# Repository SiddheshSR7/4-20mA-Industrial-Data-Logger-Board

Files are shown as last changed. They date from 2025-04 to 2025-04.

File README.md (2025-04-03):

**Project Overview: 4-20mA Industrial IoT Data Logger**

The 4-20mA Industrial IoT Data Logger is a high-precision data acquisition system designed for industrial automation, remote monitoring, and predictive maintenance applications. Engineered with robust hardware and intelligent software, this 4-layer PCB is developed using KiCad and features advanced communication protocols, real-time data logging, and IoT connectivity. This system ensures accurate monitoring of industrial processes, enabling seamless data exchange and control in demanding environments.

### **Hardware Specifications:**
- **Microcontroller:** ESP32-WROOM-S3 SoC with dual-core Xtensa LX7 processor, integrated Wi-Fi & Bluetooth connectivity, and low-power operation.
- **USB-UART Interface:** CP2102N IC enabling high-speed USB-to-serial communication for seamless programming and debugging.
- **Analog Input:** 4-channel 4-20mA analog input with high-precision ADC for industrial sensor interfacing and real-time data acquisition.
- **Relay Output:** 2-channel 24VDC fast-switching relay outputs designed for industrial control applications, supporting up to 3A load per channel.
- **Communication Interfaces:**
  - **RS232 (Full-Duplex):** Supports legacy industrial communication standards for serial device interfacing.
  - **RS485 (Half-Duplex):** Enables reliable long-distance communication in noisy industrial environments.
- **Data Storage:** SD card interface supporting high-capacity storage for logging and offline data retrieval.
- **Programming & Debugging:**
  - USB B-type connector for easy programming and firmware updates.
  - Dedicated UART debug port for real-time monitoring, diagnostics, and firmware development.
- **Power Specifications:**
  - Operating voltage: 24V DC.
  - Maximum current rating: 3A.
  - Efficient power management ensuring stable performance in industrial environments.

### **Software Features:**
- **IoT Dashboard Integration:** Secure cloud-based monitoring and control via an interactive web-based dashboard.
- **Over-the-Air (OTA) Updates:** Supports remote firmware upgrades, reducing downtime and maintenance efforts.
- **Configurable I/O:** User-defined configuration for analog input scaling and relay output control through an intuitive software interface.
- **MQTT Protocol:** Enables encrypted and reliable cloud communication, facilitating seamless data transmission for industrial automation.
- **Data Logging & Analytics:**
  - Real-time and historical data storage for trend analysis and predictive maintenance.
  - Secure SD card-based local logging for offline diagnostics.
- **Multi-Protocol Support:** Compatible with Modbus RTU, MQTT, and HTTP APIs for enhanced industrial IoT integration.

### **Applications:**
- Industrial process monitoring and control.
- Remote asset tracking and condition monitoring.
- SCADA system integration.
- Energy and utility monitoring.
- Predictive maintenance and fault detection.

The 4-20mA Industrial IoT Data Logger is a powerful solution for industrial automation, offering real-time data acquisition, secure cloud connectivity, and seamless integration into existing systems. Its combination of rugged hardware and intelligent software makes it an ideal choice for modern industrial applications requiring high accuracy, reliability, and efficiency.

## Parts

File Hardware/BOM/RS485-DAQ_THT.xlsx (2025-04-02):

Sr. No. | Reference | Value | Footprint | Qty
1 | C1 | 100uF/6.3V | Capacitor_SMD:C_0805_2012Metric_Pad1.18x1.45mm_HandSolder | 1
2 | C2 | 1uF/50V | Capacitor_SMD:C_0805_2012Metric_Pad1.18x1.45mm_HandSolder | 1
3 | C3,C5 | 1nF/50V | Capacitor_SMD:C_0805_2012Metric_Pad1.18x1.45mm_HandSolder | 2
4 | C4 | 1uF/10V | Capacitor_SMD:C_0805_2012Metric_Pad1.18x1.45mm_HandSolder | 1
5 | C6,C8,C10 | 10uF/25V | Capacitor_SMD:C_0805_2012Metric_Pad1.18x1.45mm_HandSolder | 3
6 | C7,C9 | 0.1uF/25V | Capacitor_SMD:C_0805_2012Metric_Pad1.18x1.45mm_HandSolder | 2
7 | C11,C13,C15,C16,C17,C26 | 1uF | Capacitor_SMD:C_0805_2012Metric_Pad1.18x1.45mm_HandSolder | 6
8 | C12 | 470uF 35V | Capacitor_SMD:CP_Elec_10x10.5 | 1
9 | C14 | 100uF 16V | Capacitor_SMD:CP_Elec_8x10.5 | 1
10 | C18 | 100uF 10V | Capacitor_SMD:CP_Elec_8x6.9 | 1
11 | C19,C20,C21,C22 | 1nF | Capacitor_SMD:C_0805_2012Metric_Pad1.18x1.45mm_HandSolder | 4
12 | C23,C24 | 0.1uF | Capacitor_SMD:C_0805_2012Metric_Pad1.18x1.45mm_HandSolder | 2
13 | C25 | 100nF | Capacitor_SMD:C_0805_2012Metric_Pad1.18x1.45mm_HandSolder | 1
14 | C27 | 10uF | Capacitor_SMD:C_0805_2012Metric_Pad1.18x1.45mm_HandSolder | 1
15 | CR1 | M7 | Diode_SMD:D_1210_3225Metric_Pad1.42x2.65mm_HandSolder | 1
16 | D1,D2 | ESD9B5.0ST5G | Diode_SMD:D_SOD-923 | 2
17 | D3 | S3D | S3D:S3D | 1
18 | D4,D5,D6,D7 | SMAJ18A | Diode_SMD:D_SMA | 4
19 | D8,D9,D10,D11,D12,D13,D14,D15 | 1N5819 | Diode_SMD:D_1206_3216Metric_Pad1.42x1.75mm_HandSolder | 8
20 | D16,D17 | D_Zener | Diode_SMD:D_0805_2012Metric_Pad1.15x1.40mm_HandSolder | 2
21 | D18,D19 | LED | LED_SMD:LED_1206_3216Metric_Pad1.42x1.75mm_HandSolder | 2
22 | FB1,FB2,FB3,FB4 | FerriteBead | Inductor_SMD:L_Walsin_WLFM201209x | 4
23 | J1 | 10103594-0001LF | TypeBConnector:AMPHENOL_10103594-0001LF | 1
24 | J2 | UART | Connector_PinHeader_2.54mm:PinHeader_1x04_P2.54mm_Vertical | 1
25 | J3 | 24V Input | TerminalBlock_Phoenix:TerminalBlock_Phoenix_MPT-0,5-2-2.54_1x02_P2.54mm_Horizontal | 1
26 | J4 | Analog Input | TerminalBlock_Phoenix:TerminalBlock_Phoenix_MPT-0,5-5-2.54_1x05_P2.54mm_Horizontal | 1
27 | J5 | 2_Ch. AC Devices | TerminalBlock_Phoenix:TerminalBlock_Phoenix_MPT-0,5-4-2.54_1x04_P2.54mm_Horizontal | 1
28 | J6 | DB9 | Connector_Dsub:DSUB-9_Male_Horizontal_P2.77x2.84mm_EdgePinOffset4.94mm_Housed_MountingHolesOffset7.48mm | 1
29 | J7 | RS485 | TerminalBlock_Phoenix:TerminalBlock_Phoenix_MPT-0,5-2-2.54_1x02_P2.54mm_Horizontal | 1
30 | J8 | AC Input | TerminalBlock_Phoenix:TerminalBlock_Phoenix_MPT-0,5-3-2.54_1x03_P2.54mm_Horizontal | 1
31 | J9 | Micro_SD_Card | Connector_Card:microSD_HC_Wuerth_693072010801 | 1
32 | K1,K2 | Relay_SPDT | Relay_THT:Relay_SPDT_Finder_34.51_Vertical | 2
33 | L1 | 68uH | Inductor_SMD:L_Bourns_SRP1038C_10.0x10.0mm | 1
34 | Q1,Q2 | S8050 | Package_TO_SOT_THT:TO-92_Inline | 2
35 | R1,R6,R7 | 12K | Resistor_SMD:R_0805_2012Metric_Pad1.20x1.40mm_HandSolder | 3
36 | R2,R4 | 5K | Resistor_SMD:R_0805_2012Metric_Pad1.20x1.40mm_HandSolder | 2
37 | R3,R5,R12 | 470R | Resistor_SMD:R_0805_2012Metric_Pad1.20x1.40mm_HandSolder | 3
38 | R8,R9,R10,R11 | 0R | Resistor_SMD:R_0805_2012Metric_Pad1.20x1.40mm_HandSolder | 4
39 | R13,R14,R15,R16 | 250R | Resistor_SMD:R_0805_2012Metric_Pad1.20x1.40mm_HandSolder | 4
40 | R17,R19,R20 | 330 | Resistor_SMD:R_0805_2012Metric_Pad1.20x1.40mm_HandSolder | 3
41 | R18 | 300 | Resistor_SMD:R_0805_2012Metric_Pad1.20x1.40mm_HandSolder | 1
42 | R21,R22 | 1K | Resistor_SMD:R_0805_2012Metric_Pad1.20x1.40mm_HandSolder | 2
43 | R23 | 1k | Resistor_SMD:R_0805_2012Metric_Pad1.20x1.40mm_HandSolder | 1
44 | R24,R25,R26,R27 | 10k | Resistor_SMD:R_0805_2012Metric_Pad1.20x1.40mm_HandSolder | 4
45 | R28,R29 | 20k | Resistor_SMD:R_0805_2012Metric_Pad1.20x1.40mm_HandSolder | 2
46 | R30 | 120 | Resistor_SMD:R_0805_2012Metric_Pad1.20x1.40mm_HandSolder | 1
47 | RV1 | MOV-10D201K | MOV-10D201K:MOV10D201KTR | 1
48 | SW1,SW2 | SW_Push | Button_Switch_THT:SW_PUSH_6mm_H5mm | 2
49 | U1 | ESP32-WROOM-32D | RF_Module:ESP32-WROOM-32D | 1
50 | U2 | AMS1117-3.3 | Package_TO_SOT_SMD:SOT-223-3_TabPin2 | 1
51 | U3 | CP2102N-Axx-xQFN28 | Package_DFN_QFN:QFN-28-1EP_5x5mm_P0.5mm_EP3.35x3.35mm | 1
52 | U4 | LM2596S-12 | Package_TO_SOT_SMD:TO-263-5_TabPin3 | 1
53 | U5 | MAX232 | Package_SO:SOIC-16W_5.3x10.2mm_P1.27mm | 1
54 | U6 | AMS1117-5.0 | Package_TO_SOT_SMD:SOT-223-3_TabPin2 | 1
55 | U7,U8 | LM358 | Package_SO:SOIC-8_3.9x4.9mm_P1.27mm | 2
56 | U9,U10 | PC817 | Package_DIP:DIP-4_W7.62mm | 2
57 | U11 | MAX485E | Package_SO:SOIC-8_3.9x4.9mm_P1.27mm | 1
 |  |  | Total Qnty. | 109

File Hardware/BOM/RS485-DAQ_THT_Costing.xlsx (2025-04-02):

Reference | Value | Footprint | Qty | DNP | Unit Cost | Total/PCB | Purchase | Change
BT1 | Battery_Cell | Battery:BatteryHolder_Keystone_3034_1x20mm | 1 |  | 28 | 28 | https://in.element14.com/keystone/3034/batt-holder-coil-cell-20mm-x-1/dp/4049820
C1 | 100uF/6.3V | Capacitor_SMD:C_1206_3216Metric_Pad1.33x1.80mm_HandSolder | 1 |  | 12.1 | 12.1 | https://www.ktron.in/product/100uf-6-3v-multi-layered-ceramic-capacitor/?v=c86ee0d9d7ed
C2 | 1uF/50V | Capacitor_SMD:C_1206_3216Metric_Pad1.33x1.80mm_HandSolder | 1 |  | 2.1 | 2.1 | https://www.ktron.in/product/1uf-50v-multi-layered-ceramic-capacitor/?utm_term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
C3,C5 | 1nF/50V | Capacitor_SMD:C_1206_3216Metric_Pad1.33x1.80mm_HandSolder | 2 |  | 0.5 | 1 | https://www.ktron.in/product/1nf-50v-multi-layered-ceramic-capacitor-mlcc-smd-0603/?utm_term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
C4 | 1uF/10V | Capacitor_SMD:C_1206_3216Metric_Pad1.33x1.80mm_HandSolder | 1 |  | 1.06 | 1.06 | https://evelta.com/1uf-10v-10-x5r-0402-mlcc-multilayer-ceramic-capacitor-cl05a105kp5nnnc/?gad_source=1
C6,C8,C10,C12,C13,C14,C22 | 1uF | Capacitor_SMD:C_1206_3216Metric_Pad1.33x1.80mm_HandSolder | 7 |  | 3 | 21 | https://robu.in/product/1206b105k500nt-fh-50v-1uf-x7r%C2%B110-1206-multilayer-ceramic-capacitors-mlcc-smd-smt-rohs/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
C7 | 10uF/25V | Capacitor_SMD:CP_Elec_4x5.3 | 1 |  | 2 | 2 | https://www.ktron.in/product/25v-10uf-electrolytic-capacitor-smd/?utm_term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
C9 | 470uF 35V | Capacitor_SMD:CP_Elec_10x10.5 | 1 |  | 6 | 6 | https://robu.in/product/hy1v471mc100105meo-hyncdz-470uf-35v-480ma120hz-%C2%B120-smdd10xl10-5mm-aluminum-electrolytic-capacitors-smd-rohs/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
C11 | 100uF 16V | Capacitor_SMD:CP_Elec_8x10.5 | 1 |  |  | 0 |  | Y
C15 | 100uF 10V | Capacitor_SMD:CP_Elec_5x5.4 | 1 |  | 2 | 2 | https://robu.in/product/hy1a101mc050054meo-hyncdz-100uf-10v-50ma120hz-%C2%B120-smdd5xl5-4mm-aluminum-electrolytic-capacitors-smd-rohs/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
C16,C17,C18,C19 | 1nF | Capacitor_SMD:C_1206_3216Metric_Pad1.33x1.80mm_HandSolder | 4 |  | 6.61 | 26.44 | https://evelta.com/1-nf-500v-1206-smd-multilayer-ceramic-capacitors-cc1206kkx7rbbb102-yageo/
C20,C21 | 0.1uF | Capacitor_SMD:C_1206_3216Metric_Pad1.33x1.80mm_HandSolder | 2 |  | 2 | 4 | https://robu.in/product/0-1uf-capacitor-smdc-1206/
C23 | 10uF | Capacitor_SMD:C_1206_3216Metric_Pad1.33x1.80mm_HandSolder | 1 |  | 2 | 2 | https://robu.in/product/cs3216x7r106k160nri-samwha-16v-10uf-x7r-1206-multilayer-ceramic-capacitors-mlcc-smd-smt-rohs/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
CR1 | M7 | Diode_SMD:D_1210_3225Metric_Pad1.42x2.65mm_HandSolder | 1 |  | 1.36 | 1.36 | https://evelta.com/m7-1a-glass-passivated-rectifier-diode-sma/?gad_source=1
D1 | S3D | S3D:S3D | 1 |  | 17.5 | 17.5 | https://www.digikey.in/en/products/detail/diotec-semiconductor/S3D/21380521?productid=21380521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
D2,D3,D4,D5 | SMAJ18A | Diode_SMD:D_SMA | 4 |  | 7.5 | 30 | https://www.arrow.com/en/products/smaj18ar3g/taiwan-semiconductor
D6,D7,D8,D9,D10,D11,D12,D13 | 1N5819 | Diode_SMD:D_1206_3216Metric_Pad1.42x1.75mm_HandSolder | 8 |  | 4.64 | 37.12 | https://evelta.com/1n5819hw-7-f-40v-1a-schottky-barrier-rectifier-diode-2pin-sod123/?gad_source=1
D14,D15 | D_Zener | Diode_SMD:D_1206_3216Metric_Pad1.42x1.75mm_HandSolder | 2 |  | 2 | 4 | https://robu.in/product/bzv55-c24115-nexperia-zener-diode-24-v-500-mw-%C2%B15-surface-mount-sod-80-mini-melf-do-213ac-llds/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
D16,D17 | LED | LED_SMD:LED_1206_3216Metric_Pad1.42x1.75mm_HandSolder | 2 |  | 2.8 | 5.6 | https://evelta.com/green-led-smd-1206-package/?gad_source=1
FB1,FB2,FB3,FB4 | FerriteBead | Inductor_SMD:L_Walsin_WLFM201209x | 4 |  | 0.94 | 3.76 | https://robu.in/product/blm18ag121sn1d-murata-ferrite-beads-multi-layer-120ohm-25-100mhz-0-8a-0-18ohm-dcr-0603-t-r/ | Y
J1 | 24V Input | Connector_BarrelJack:BarrelJack_Horizontal | 1 |  | 1.96 | 1.96 | https://robu.in/product/dc-jack-005/?gad_source=1
J2 | Analog Input | TerminalBlock_Phoenix:TerminalBlock_Phoenix_MPT-0,5-5-2.54_1x05_P2.54mm_Horizontal | 1 |  |  | 0
J3 | 2_Ch. AC Devices | TerminalBlock_Phoenix:TerminalBlock_Phoenix_MPT-0,5-4-2.54_1x04_P2.54mm_Horizontal | 1 |  |  | 0
J4 | DB9 | Connector_Dsub:DSUB-9_Male_Horizontal_P2.77x2.84mm_EdgePinOffset4.94mm_Housed_MountingHolesOffset7.48mm | 1 |  | 12.39 | 12.39 | https://evelta.com/db9-male-connector-right-angle-pcb-mounting/?gad_source=1
J5 | RS485 | TerminalBlock_Phoenix:TerminalBlock_Phoenix_MPT-0,5-2-2.54_1x02_P2.54mm_Horizontal | 1 |  |  | 0
J6 | AC Input | TerminalBlock_Phoenix:TerminalBlock_Phoenix_MPT-0,5-3-2.54_1x03_P2.54mm_Horizontal | 1 |  |  | 0
K1,K2 | Relay_SPDT | Relay_THT:Relay_SPDT_hongfa-hf3ff | 2 |  | 34.22 | 68.44 | https://evelta.com/hongfa-hf3ff-series-10a-spdt-24vdc-pcb-mount-sealed-subminiature-high-power-relay/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
L1 | 68uH | Inductor_SMD:L_Bourns_SRP1038C_10.0x10.0mm | 1 |  |  | 0
R1 | 12K | Resistor_SMD:R_1206_3216Metric_Pad1.30x1.75mm_HandSolder | 1 |  | 0.1 | 0.1 | https://www.hnhcart.com/products/12k-ohm-smd-resistor-1206-pack-of-100?gad_source=1
R2 | 5K | Resistor_SMD:R_1206_3216Metric_Pad1.30x1.75mm_HandSolder | 1 |  | 0.2 | 0.2 | https://www.hnhcart.com/products/5-1k-ohm-smd-resistor-1206-pack-of-100?gad_source=1
R3,R4 | 470R | Resistor_SMD:R_1206_3216Metric_Pad1.30x1.75mm_HandSolder | 2 |  | 0.65 | 1.3 | https://robu.in/product/470-ohm-1-4w-1206-surface-mount-chip-resistor-pack-of-100/?gad_source=1
R5 | 10K | Resistor_SMD:R_1206_3216Metric_Pad1.30x1.75mm_HandSolder | 1 |  | 0.69 | 0.69 | https://robu.in/product/10k-ohm-1-4w-1206-surface-mount-chip-resistor-pack-of-100/?gad_source=1
R6 | 22R | Resistor_SMD:R_1206_3216Metric_Pad1.30x1.75mm_HandSolder | 1 |  | 0.59 | 0.59 | https://robu.in/product/22-ohm-1-4w-1206-surface-mount-chip-resistor-pack-of-100/?gad_source=1
R7,R8,R19,R20,R21,R22 | 10k | Resistor_SMD:R_1206_3216Metric_Pad1.30x1.75mm_HandSolder | 6 |  | 0.69 | 4.14 | https://robu.in/product/10k-ohm-1-4w-1206-surface-mount-chip-resistor-pack-of-100/?gad_source=1
R9,R10,R11,R12 | 250R | Resistor_SMD:R_1206_3216Metric_Pad1.30x1.75mm_HandSolder | 4 |  |  | 0 |  | Y
R13,R15,R16 | 330 | Resistor_SMD:R_1206_3216Metric_Pad1.30x1.75mm_HandSolder | 3 |  | 0.65 | 1.95 | https://robu.in/product/330-ohm-1-4w-1206-surface-mount-chip-resistor-pack-of-100/?gad_source=1
R14 | 300 | Resistor_SMD:R_1206_3216Metric_Pad1.30x1.75mm_HandSolder | 1 |  | 1 | 1 | https://robu.in/product/rc1206jr-07300rl-yageo-smd-chip-resistor-300-ohm-%C2%B1-5-250-mw-1206-3216-metric-thick-film-general-purpose/
R17,R18 | 4.7K | Resistor_SMD:R_1206_3216Metric_Pad1.30x1.75mm_HandSolder | 2 |  | 0.65 | 1.3 | https://robu.in/product/4-7k-ohm-1-4w-1206-surface-mount-chip-resistor-pack-of-100/?gad_source=1
R23,R24 | 20k | Resistor_SMD:R_1206_3216Metric_Pad1.30x1.75mm_HandSolder | 2 |  | 0.51 | 1.02 | https://robu.in/product/rc1206fr-0720kl-yageo-res-thick-film-1206-20k-ohm-1-0-25w1-4w-%C2%B1100ppm-c-pad-smd-t-r/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
R25 | 120 | Resistor_SMD:R_1206_3216Metric_Pad1.30x1.75mm_HandSolder | 1 |  | 0.51 | 0.51 | https://robu.in/product/rc1206fr-07120rl-yageo-res-thick-film-1206-120-ohm-1-0-25w1-4w-%C2%B1100ppm-c-pad-smd-t-r/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
RV1 | MOV-10D201K | MOV-10D201K:MOV10D201KTR | 1 |  |  | 0
SW1,SW2 | SW_Push | Button_Switch_THT:SW_PUSH_6mm_H5mm | 2 |  | 1.6 | 3.2 | https://robu.in/product/6x6x5-tactile-push-button-switch/?gad_source=1
TP1 | GND | TestPoint:TestPoint_THTPad_D1.0mm_Drill0.5mm | 1 |  |  | 0
TP2 | TX_TP | TestPoint:TestPoint_THTPad_D1.0mm_Drill0.5mm | 1 |  |  | 0
TP3 | RX_TP | TestPoint:TestPoint_THTPad_D1.0mm_Drill0.5mm | 1 |  |  | 0
TP4 | +3.3V_TP | TestPoint:TestPoint_THTPad_D1.0mm_Drill0.5mm | 1 |  |  | 0
TP5 | +12V_TP | TestPoint:TestPoint_THTPad_D1.0mm_Drill0.5mm | 1 |  |  | 0
TP6 | +5V_TP | TestPoint:TestPoint_THTPad_D1.0mm_Drill0.5mm | 1 |  |  | 0
U1 | ESP32-S3-WROOM-1 | RF_Module:ESP32-S3-WROOM-1 | 1 |  | 289 | 289 | https://robu.in/product/espressif-esp32-s3-wroom-1-n4r8-modules/?gad_source=1
U2 | w25q64jvssiq | Package_SO:SOIC-8_5.23x5.23mm_P1.27mm | 1 |  | 66.9 | 66.9 | https://www.ktron.in/product/w25q64jvssiq-serial-flash/?utm_term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
U3 | AMS1117-3.3 | Package_TO_SOT_SMD:SOT-223-3_TabPin2 | 1 |  | 11 | 11 | https://robu.in/product/ams1117-3-3v-1a-sot-223-voltage-regulator-ic-pack-of-5-ics/?gad_source=1
U4 | LM2596S-12 | Package_TO_SOT_SMD:TO-263-5_TabPin3 | 1 |  | 22 | 22 | https://www.ktron.in/product/lm2596-12v-step-down-regulator/?utm_term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
U5 | MAX232 | Package_SO:SOIC-16W_5.3x10.2mm_P1.27mm | 1 |  | 25 | 25 | https://robu.in/product/max232cse-soic-narrow-16-rs-232-interface-ic-pack-of-2-ics/?gad_source=1
U6 | AMS1117-5.0 | Package_TO_SOT_SMD:SOT-223-3_TabPin2 | 1 |  | 5.2 | 5.2 | https://www.ktron.in/product/ams1117-5v-voltage-regulator-sot-223/?utm_term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
U7 | DS1307ZN+ | Package_SO:SOIC-8_3.9x4.9mm_P1.27mm | 1 |  | 120 | 120 | https://robu.in/product/ds1307zntr-analog-devices-rtc-ic-date-time-format-day-date-month-year-hhmmss-i2c-4-5-v-to-5-5-v-supply-soic-8/
U8,U9 | LM358 | Package_SO:SOIC-8_3.9x4.9mm_P1.27mm | 2 |  |  | 0
U10,U11 | PC817 | Package_DIP:DIP-4_W7.62mm | 2 |  | 3.54 | 7.08 | https://www.ktron.in/product/pc817-optocoupler-sharp-dip-4/?v=c86ee0d9d7ed
U12 | MAX485E | Package_SO:SOIC-8_3.9x4.9mm_P1.27mm | 1 |  | 78 | 78 | https://robu.in/product/max13485eesa-analog-devices-max13485eesa-500kbps-rs-485-422-half-duplex-transceiver-4-75v-5-25v-supply-soic-8/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
Y1 | 32.768KHz | Crystal:Crystal_SMD_Qantek_QC5CB-2Pin_5x3.2mm | 1 |  | 12.39 | 12.39 | https://evelta.com/yt-26-32-768khz-12-5pf-10ppm-2pin-dip-through-hole-cylinder-crystal/?gad_source=1 | Y
 |  |  | 102 |  |  | 948

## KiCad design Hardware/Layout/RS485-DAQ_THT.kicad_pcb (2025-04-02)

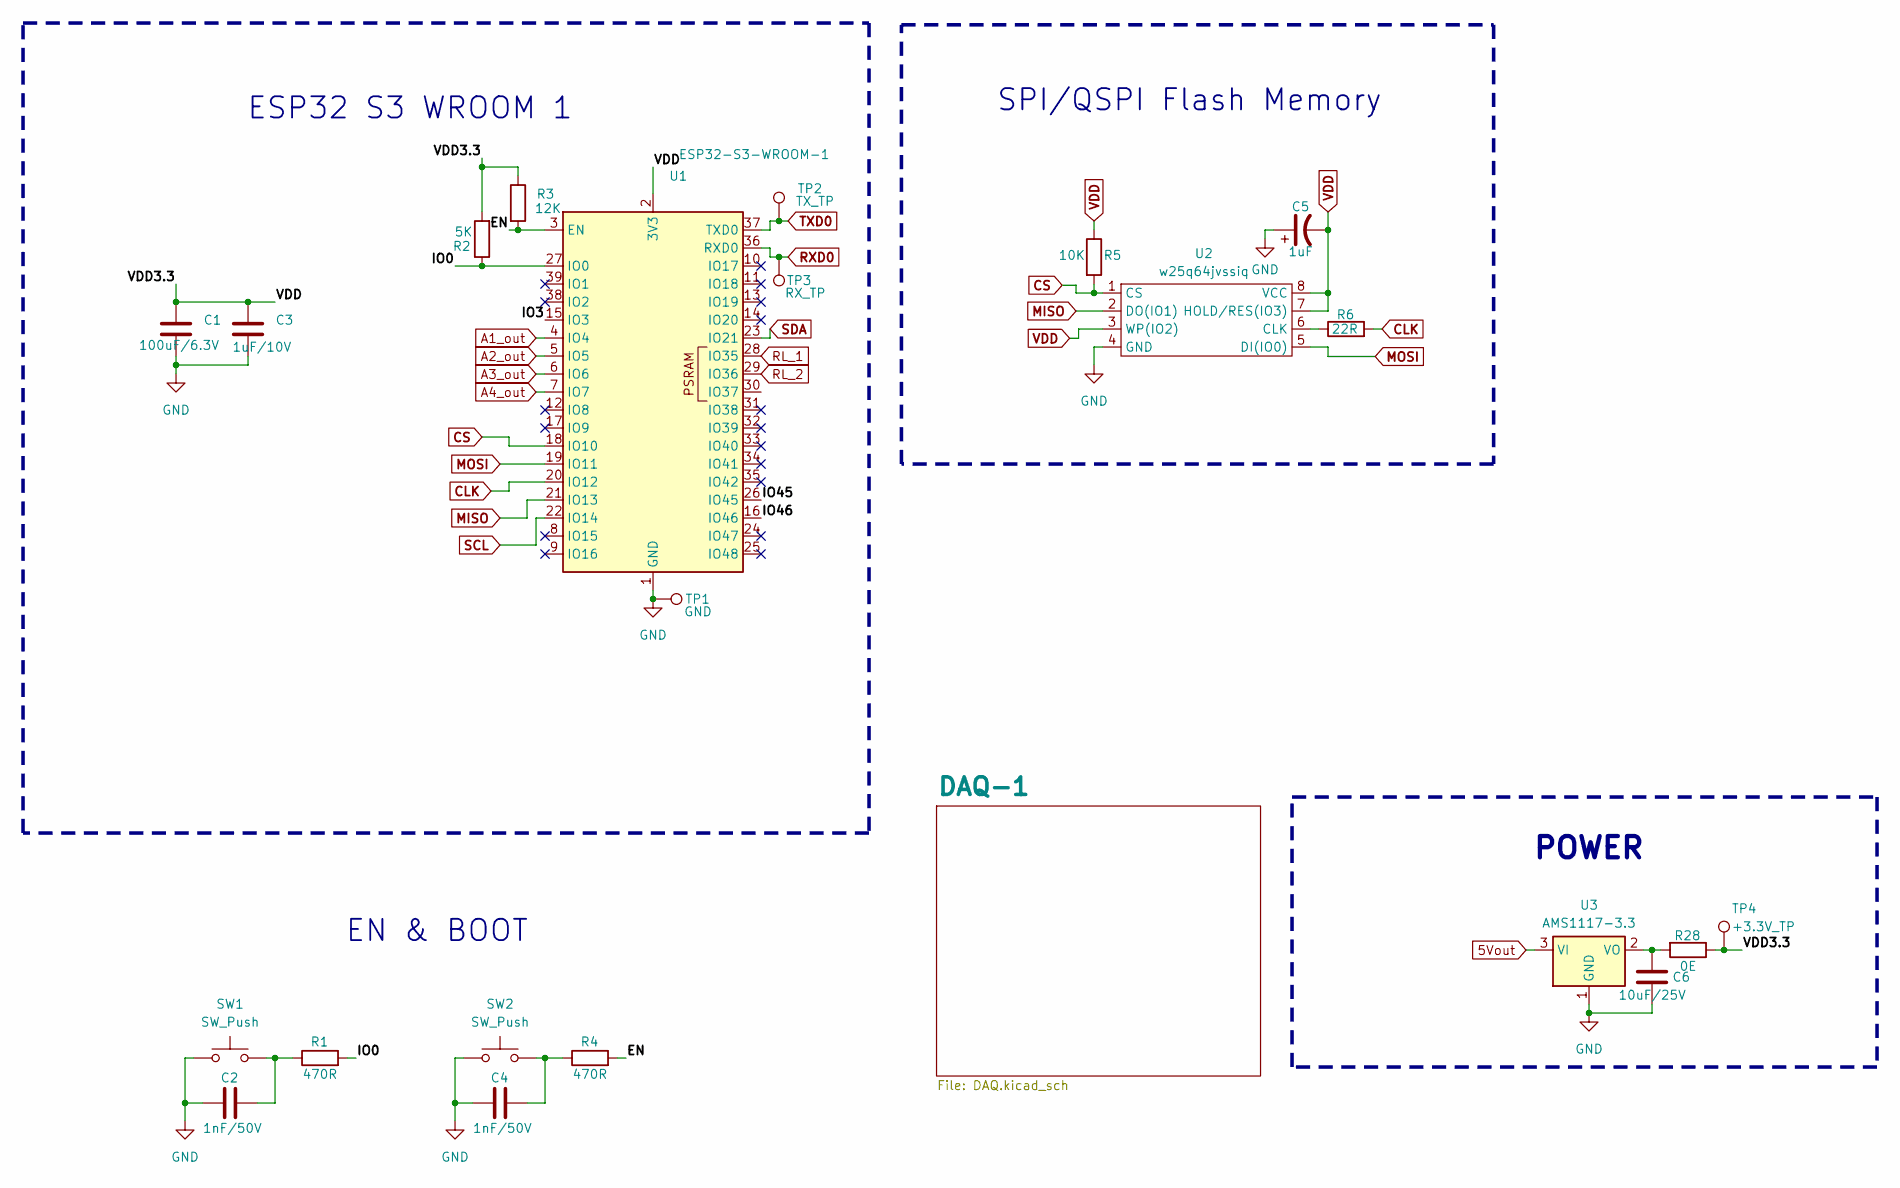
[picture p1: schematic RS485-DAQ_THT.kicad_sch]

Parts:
C1: 100uF/6.3V; C_1206_3216Metric_Pad1.33x1.80mm_HandSolder
C2, C4: 1nF/50V; C_1206_3216Metric_Pad1.33x1.80mm_HandSolder
C3: 1uF/10V; C_1206_3216Metric_Pad1.33x1.80mm_HandSolder
C5: 1uF; C_1206_3216Metric_Pad1.33x1.80mm_HandSolder
C6: 10uF/25V; CP_Elec_4x5.3
R1, R4: 470R; R_1206_3216Metric_Pad1.30x1.75mm_HandSolder
R2: 5K; R_1206_3216Metric_Pad1.30x1.75mm_HandSolder
R3: 12K; R_1206_3216Metric_Pad1.30x1.75mm_HandSolder
R5: 10K; R_1206_3216Metric_Pad1.30x1.75mm_HandSolder
R6: 22R; R_1206_3216Metric_Pad1.30x1.75mm_HandSolder
R28: 0E; R_1206_3216Metric_Pad1.30x1.75mm_HandSolder
SW1, SW2: SW_Push; SW_PUSH_6mm_H5mm
TP1: GND; TestPoint_THTPad_D1.0mm_Drill0.5mm
TP2: TX_TP; TestPoint_THTPad_D1.0mm_Drill0.5mm
TP3: RX_TP; TestPoint_THTPad_D1.0mm_Drill0.5mm
TP4: +3.3V_TP; TestPoint_THTPad_D1.0mm_Drill0.5mm
U1: ESP32-S3-WROOM-1
U2: w25q64jvssiq; SOIC-8_5.23x5.23mm_P1.27mm
U3: AMS1117-3.3; SOT-223-3_TabPin2

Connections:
5Vout: U3.3 (VI); also elsewhere on the board
/EN: R3.2, R4.2, U1.3 (EN)
/IO0: R1.2, R2.1, U1.27 (IO0)
/IO3: U1.15 (IO3)
/IO45: U1.26 (IO45)
/IO46: U1.16 (IO46)
A1_out: U1.4 (IO4); also elsewhere on the board
A2_out: U1.5 (IO5); also elsewhere on the board
A3_out: U1.6 (IO6); also elsewhere on the board
A4_out: U1.7 (IO7); also elsewhere on the board
CLK: R6.2, U1.20 (IO12)
CS: R5.2, U1.18 (IO10), U2.1 (CS)
GND: C1.2, C2.1, C3.2, C4.1, C5.1, C6.2, SW1.1, SW2.1, TP1.1, U1.1 (GND), U1.40 (GND), U1.41 (GND), U2.4 (GND), U3.1 (GND); also elsewhere on the board
MISO: U1.21 (IO13), U2.2 (DO(IO1))
MOSI: U1.19 (IO11), U2.5 (DI(IO0))
unnamed: C2.2, R1.1, SW1.2
unnamed: C4.2, R4.1, SW2.2
unnamed: R6.1, U2.6 (CLK)
unnamed: C6.1, R28.2, U3.2 (VO)
RL_1: U1.28 (IO35); also elsewhere on the board
RL_2: U1.29 (IO36); also elsewhere on the board
RXD0: TP3.1, U1.36 (RXD0); also elsewhere on the board
SCL: U1.22 (IO14); also elsewhere on the board
SDA: U1.23 (IO21); also elsewhere on the board
TXD0: TP2.1, U1.37 (TXD0); also elsewhere on the board
VDD: C1.1, C3.1, C5.2, R2.2, R3.1, R5.1, R28.1, TP4.1, U1.2 (3V3), U2.3 (WP(IO2)), U2.7 (HOLD/RES(IO3)), U2.8 (VCC)

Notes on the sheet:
POWER
SPI/QSPI Flash Memory
ESP32 S3 WROOM 1
EN & BOOT

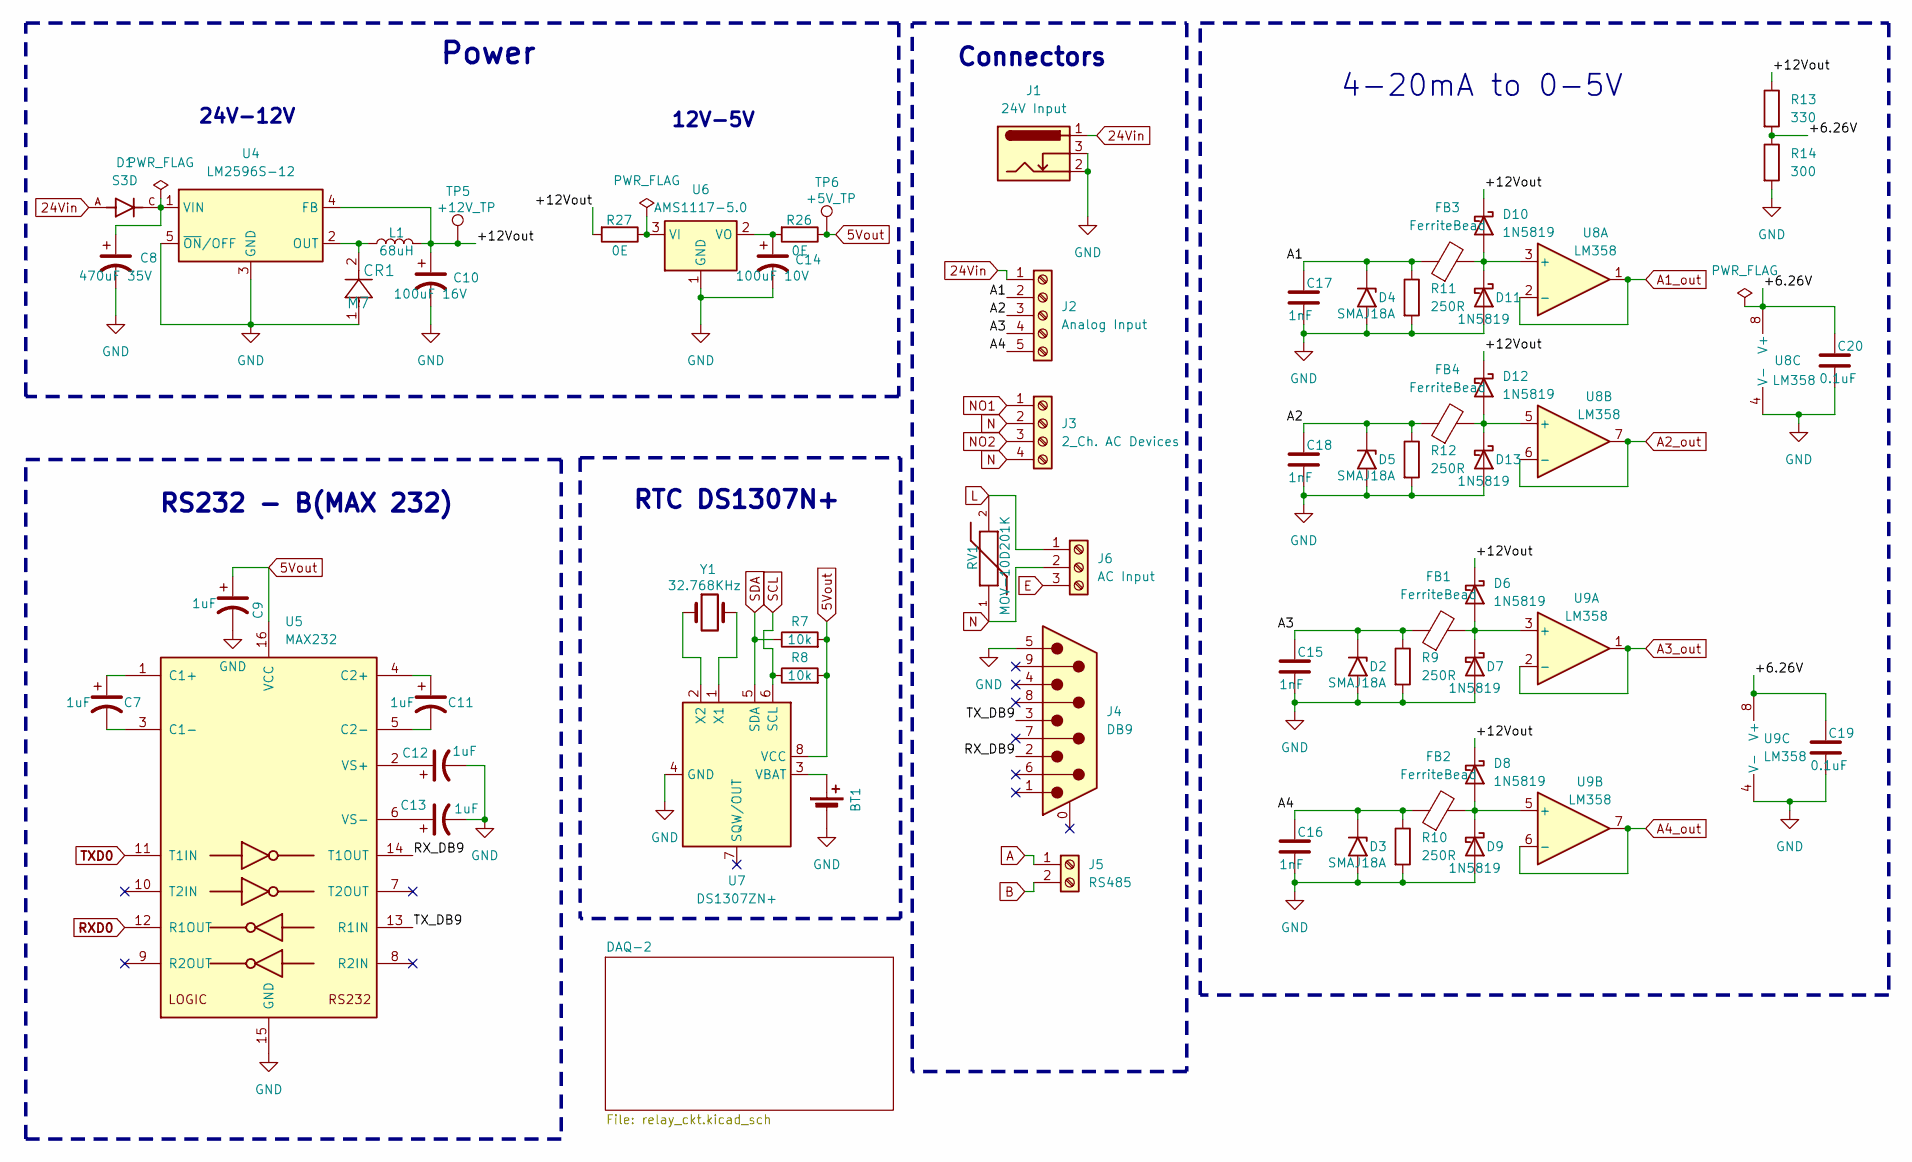
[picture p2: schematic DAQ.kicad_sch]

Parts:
BT1: Battery_Cell; BatteryHolder_Keystone_3034_1x20mm
C7, C9, C11, C12, C13: 1uF; C_1206_3216Metric_Pad1.33x1.80mm_HandSolder
C8: 470uF 35V; CP_Elec_10x10.5
C10: 100uF 16V; CP_Elec_8x10.5
C14: 100uF 10V; CP_Elec_5x5.4
C15, C16, C17, C18: 1nF; C_1206_3216Metric_Pad1.33x1.80mm_HandSolder
C19, C20: 0.1uF; C_1206_3216Metric_Pad1.33x1.80mm_HandSolder
CR1: M7; D_SMA
D1: S3D; D_SMC; PARTREV O2301
D2, D3, D4, D5: SMAJ18A; D_SMA
D6, D7, D8, D9, D10, D11, D12, D13: 1N5819; D_1206_3216Metric_Pad1.42x1.75mm_HandSolder
FB1, FB2, FB3, FB4: FerriteBead; L_Walsin_WLFM201209x
J1: 24V Input; BarrelJack_Horizontal
J2: Analog Input; TerminalBlock_Phoenix_MPT-0,5-5-2.54_1x05_P2.54mm_Horizontal
J3: 2_Ch. AC Devices; TerminalBlock_Phoenix_MPT-0,5-4-2.54_1x04_P2.54mm_Horizontal
J4: DB9; DSUB-9_Male_Horizontal_P2.77x2.84mm_EdgePinOffset4.94mm_Hou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
J5: RS485; TerminalBlock_Phoenix_MPT-0,5-2-2.54_1x02_P2.54mm_Horizontal
J6: AC Input; TerminalBlock_Phoenix_MPT-0,5-3-2.54_1x03_P2.54mm_Horizontal
L1: 68uH; L_Bourns_SRP1038C_10.0x10.0mm
R7, R8: 10k; R_1206_3216Metric_Pad1.30x1.75mm_HandSolder
R9, R10, R11, R12: 250R; R_1206_3216Metric_Pad1.30x1.75mm_HandSolder
R13: 330; R_1206_3216Metric_Pad1.30x1.75mm_HandSolder
R14: 300; R_1206_3216Metric_Pad1.30x1.75mm_HandSolder
R26, R27: 0E; R_1206_3216Metric_Pad1.30x1.75mm_HandSolder
RV1: MOV-10D201K; MOV10D201KTR; MOUSER_PART_NUMBER 652-MOV-10D201K
TP5: +12V_TP; TestPoint_THTPad_D1.0mm_Drill0.5mm
TP6: +5V_TP; TestPoint_THTPad_D1.0mm_Drill0.5mm
U4: LM2596S-12; TO-263-5_TabPin3
U5: MAX232; SOIC-16W_5.3x10.2mm_P1.27mm
U6: AMS1117-5.0; SOT-223-3_TabPin2
U7: DS1307ZN+; SOIC-8_3.9x4.9mm_P1.27mm
U8, U9: LM358; SOIC-8_3.9x4.9mm_P1.27mm
Y1: 32.768KHz; Crystal_SMD_Qantek_QC5CB-2Pin_5x3.2mm

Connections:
5Vout: C9.1, R7.2, R8.2, R26.1, TP6.1, U5.16 (VCC), U7.8 (VCC); also elsewhere on the board
24Vin: D1.A, J1.1, J2.1; also elsewhere on the board
/DAQ-1/+6.26V: C19.1, C20.1, R13.2, R14.1, U8.8 (V+), U9.8 (V+)
/DAQ-1/+12Vout: C10.1, D6.1 (K), D8.1 (K), D10.1 (K), D12.1 (K), L1.2, R13.1, R27.2, TP5.1, U4.4 (FB)
/DAQ-1/A1: C17.1, D4.1 (A1), FB3.1, J2.2, R11.1
/DAQ-1/A2: C18.1, D5.1 (A1), FB4.1, J2.3, R12.1
/DAQ-1/A3: C15.1, D2.1 (A1), FB1.1, J2.4, R9.1
/DAQ-1/A4: C16.1, D3.1 (A1), FB2.1, J2.5, R10.1
/DAQ-1/RX_DB9: J4.2, U5.14 (T1OUT)
/DAQ-1/TX_DB9: J4.3, U5.13 (R1IN)
A: J5.1; also elsewhere on the board
A1_out: U8.1, U8.2 (-); also elsewhere on the board
A2_out: U8.6 (-), U8.7; also elsewhere on the board
A3_out: U9.1, U9.2 (-); also elsewhere on the board
A4_out: U9.6 (-), U9.7; also elsewhere on the board
B: J5.2; also elsewhere on the board
E: J6.3
GND: BT1.2 (-), C8.2, C9.2, C10.2, C12.2, C13.2, C14.2, C15.2, C16.2, C17.2, C18.2, C19.2, C20.2, CR1.1, D2.2 (A2), D3.2 (A2), D4.2 (A2), D5.2 (A2), D7.2 (A), D9.2 (A), D11.2 (A), D13.2 (A), J1.2, J1.3, J4.5, R9.2, R10.2, R11.2, R12.2, R14.2, U4.3 (GND), U4.5 (~ON/OFF), U5.15 (GND), U6.1 (GND), U7.4 (GND), U8.4 (V-), U9.4 (V-); also elsewhere on the board
L: J6.1, RV1.2; also elsewhere on the board
N: J3.2, J3.4, J6.2, RV1.1
NO1: J3.1; also elsewhere on the board
NO2: J3.3; also elsewhere on the board
unnamed: BT1.1 (+), U7.3 (VBAT)
unnamed: D6.2 (A), D7.1 (K), FB1.2, U9.3 (+)
unnamed: D8.2 (A), D9.1 (K), FB2.2, U9.5 (+)
unnamed: D10.2 (A), D11.1 (K), FB3.2, U8.3 (+)
unnamed: D12.2 (A), D13.1 (K), FB4.2, U8.5 (+)
unnamed: CR1.2, L1.1, U4.2 (OUT)
unnamed: C8.1, D1.C, U4.1 (VIN)
unnamed: C7.1, U5.1 (C1+)
unnamed: C7.2, U5.3 (C1-)
unnamed: C11.1, U5.4 (C2+)
unnamed: C11.2, U5.5 (C2-)
unnamed: C12.1, U5.2 (VS+)
unnamed: C13.1, U5.6 (VS-)
unnamed: R27.1, U6.3 (VI)
unnamed: C14.1, R26.2, U6.2 (VO)
unnamed: U7.1 (X1), Y1.2
unnamed: U7.2 (X2), Y1.1
RXD0: U5.12 (R1OUT); also elsewhere on the board
SCL: R8.1, U7.6 (SCL); also elsewhere on the board
SDA: R7.1, U7.5 (SDA); also elsewhere on the board
TXD0: U5.11 (T1IN); also elsewhere on the board

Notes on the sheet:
RTC DS1307N+
RS232 - B(MAX 232)
Connectors
4-20mA to 0-5V
12V-5V
Power
24V-12V

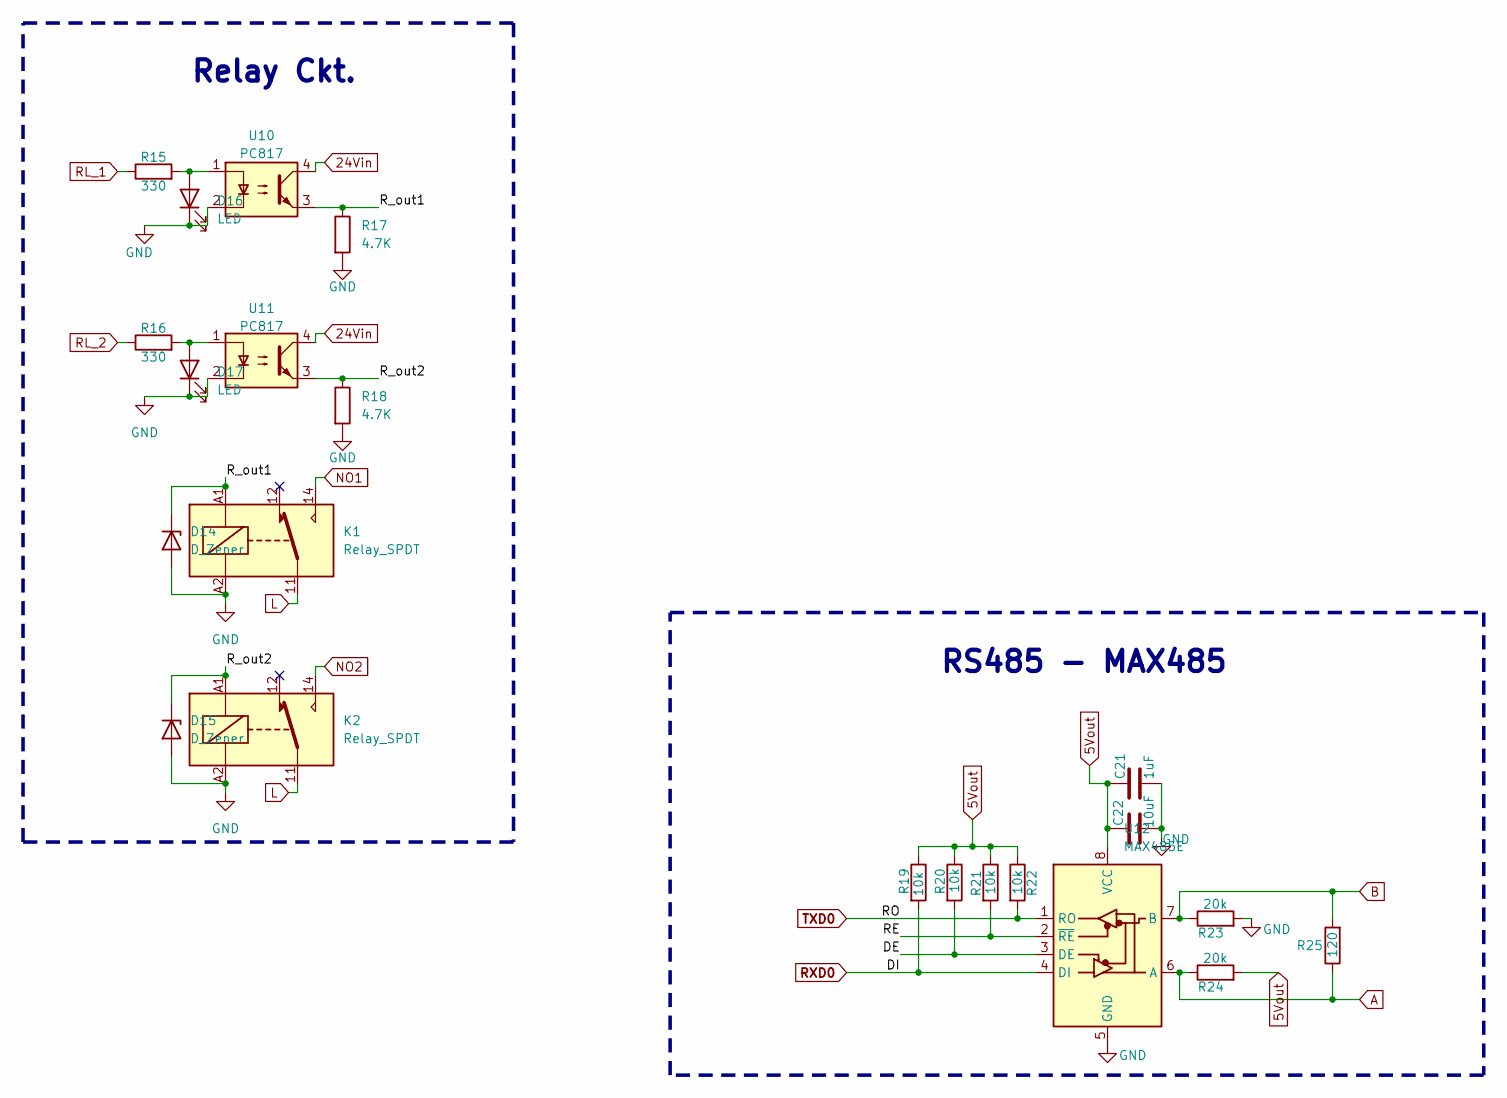
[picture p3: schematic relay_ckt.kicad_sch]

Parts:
C21: 1uF; C_1206_3216Metric_Pad1.33x1.80mm_HandSolder
C22: 10uF; C_1206_3216Metric_Pad1.33x1.80mm_HandSolder
D14, D15: D_Zener; D_MiniMELF
D16, D17: LED; LED_1206_3216Metric_Pad1.42x1.75mm_HandSolder
K1, K2: Relay_SPDT; Relay_SPDT_Hongfa_HF3F-L-xx-1ZL1T
R15, R16: 330; R_1206_3216Metric_Pad1.30x1.75mm_HandSolder
R17, R18: 4.7K; R_1206_3216Metric_Pad1.30x1.75mm_HandSolder
R19, R20, R21, R22: 10k; R_1206_3216Metric_Pad1.30x1.75mm_HandSolder
R23, R24: 20k; R_1206_3216Metric_Pad1.30x1.75mm_HandSolder
R25: 120; R_1206_3216Metric_Pad1.30x1.75mm_HandSolder
U10, U11: PC817; DIP-4_W7.62mm
U12: MAX485E; SOIC-8_3.9x4.9mm_P1.27mm

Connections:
5Vout: C21.1, C22.1, R19.1, R20.1, R21.1, R22.1, R24.2, U12.8 (VCC); also elsewhere on the board
24Vin: U10.4, U11.4; also elsewhere on the board
/DAQ-1/DAQ-2/DE: R20.2, U12.3 (DE)
/DAQ-1/DAQ-2/RE: R21.2, U12.2 (~RE)
/DAQ-1/DAQ-2/R_out1: D14.1 (K), K1.A1, R17.1, U10.3
/DAQ-1/DAQ-2/R_out2: D15.1 (K), K2.A1, R18.1, U11.3
A: R24.1, R25.1, U12.6 (A); also elsewhere on the board
B: R23.1, R25.2, U12.7 (B); also elsewhere on the board
GND: C21.2, C22.2, D14.2 (A), D15.2 (A), D16.1 (K), D17.1 (K), K1.A2, K2.A2, R17.2, R18.2, R23.2, U10.2, U11.2, U12.5 (GND); also elsewhere on the board
L: K1.11, K2.11; also elsewhere on the board
NO1: K1.14; also elsewhere on the board
NO2: K2.14; also elsewhere on the board
unnamed: D16.2 (A), R15.2, U10.1
unnamed: D17.2 (A), R16.2, U11.1
RL_1: R15.1; also elsewhere on the board
RL_2: R16.1; also elsewhere on the board
RXD0: R19.2, U12.4 (DI); also elsewhere on the board
TXD0: R22.2, U12.1 (RO); also elsewhere on the board

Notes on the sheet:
RS485 - MAX485
Relay Ckt.

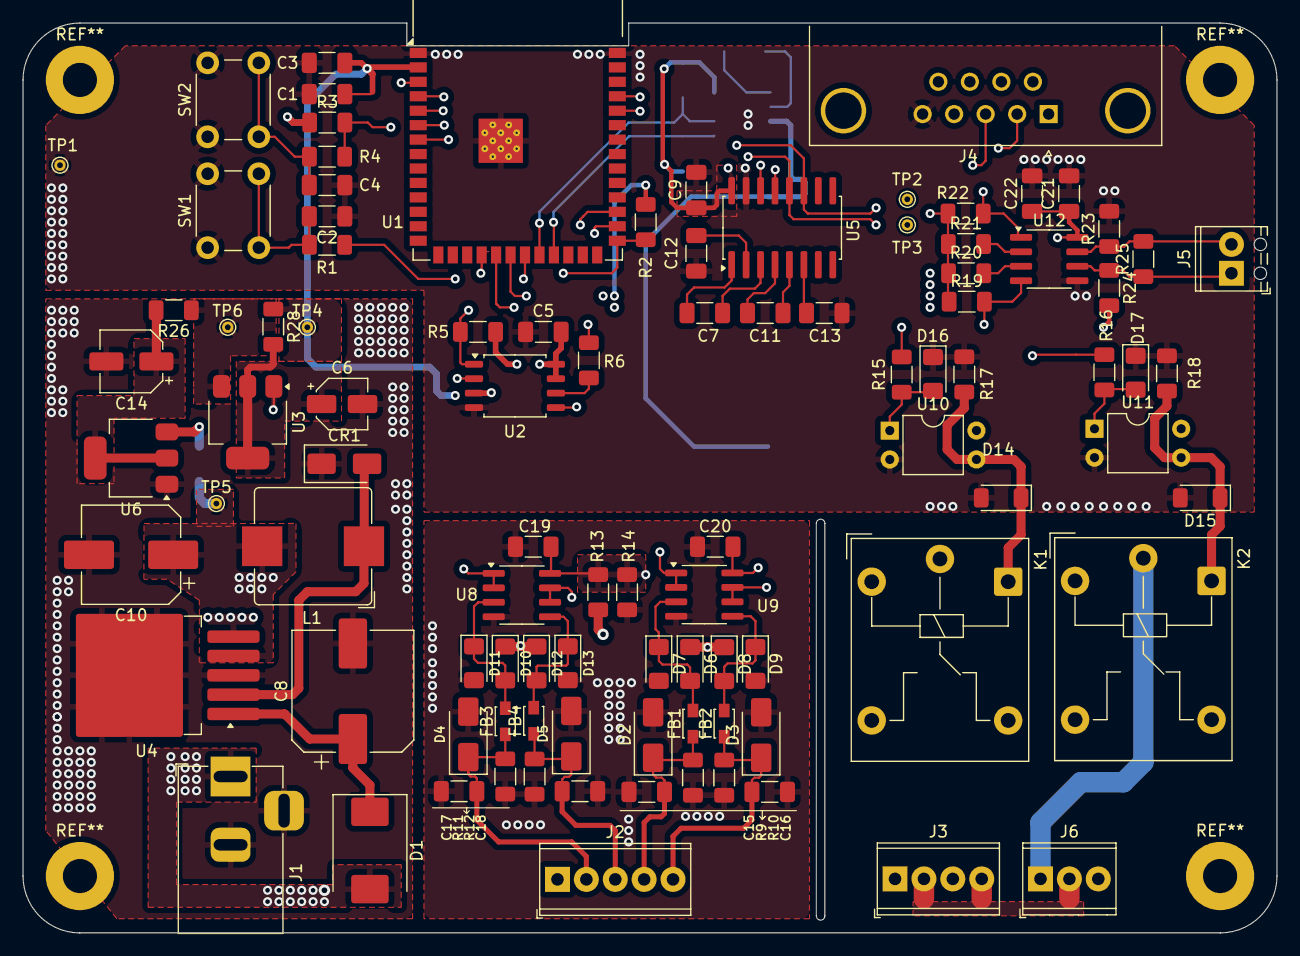
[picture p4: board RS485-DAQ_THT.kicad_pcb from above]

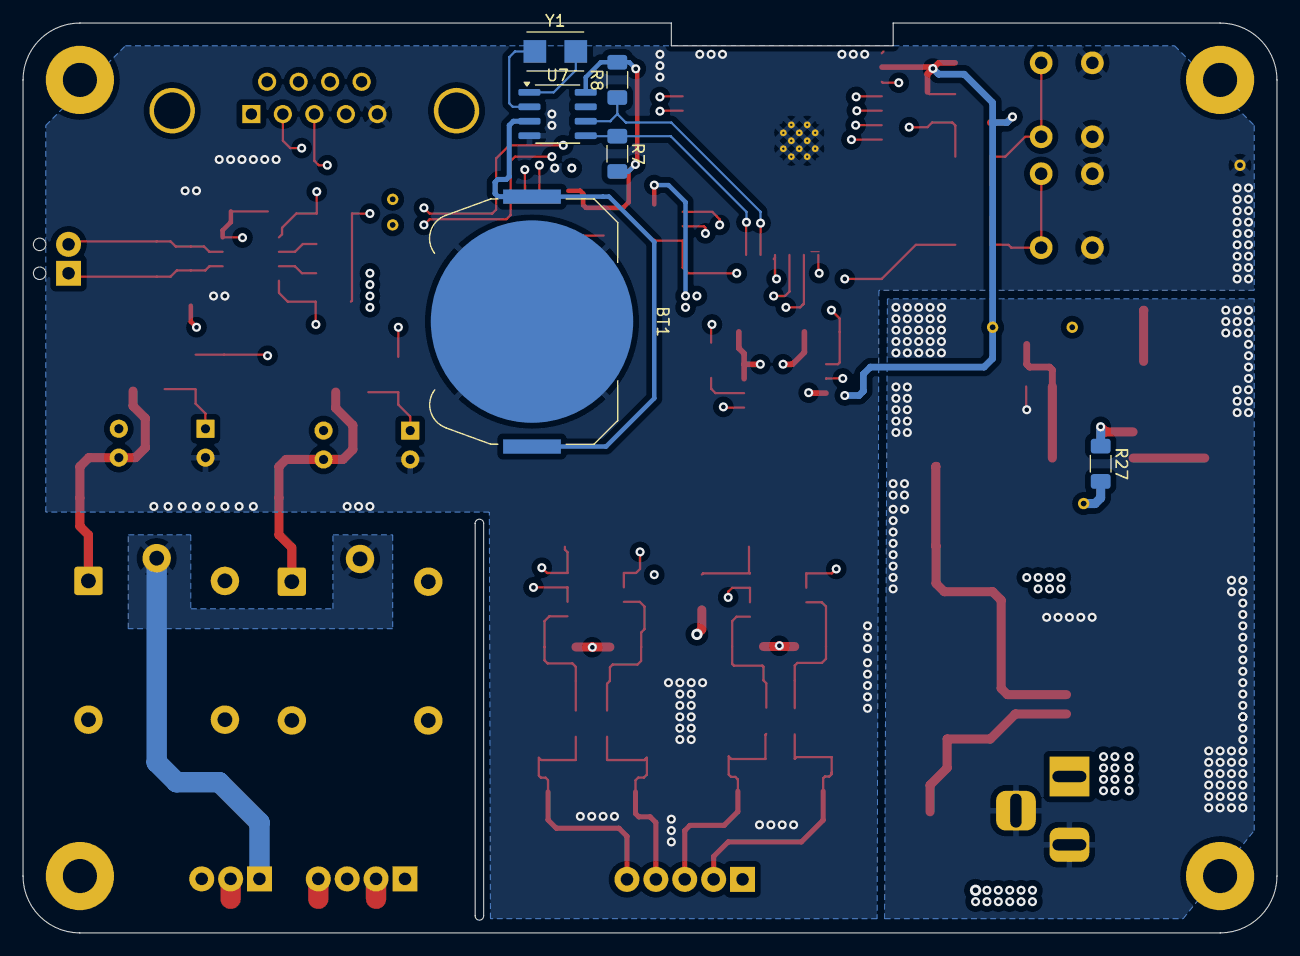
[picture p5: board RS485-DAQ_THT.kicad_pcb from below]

Board: 4 copper layers, 110.2 x 80.0 mm, 103 parts (6 on the bottom side), 61 nets.
